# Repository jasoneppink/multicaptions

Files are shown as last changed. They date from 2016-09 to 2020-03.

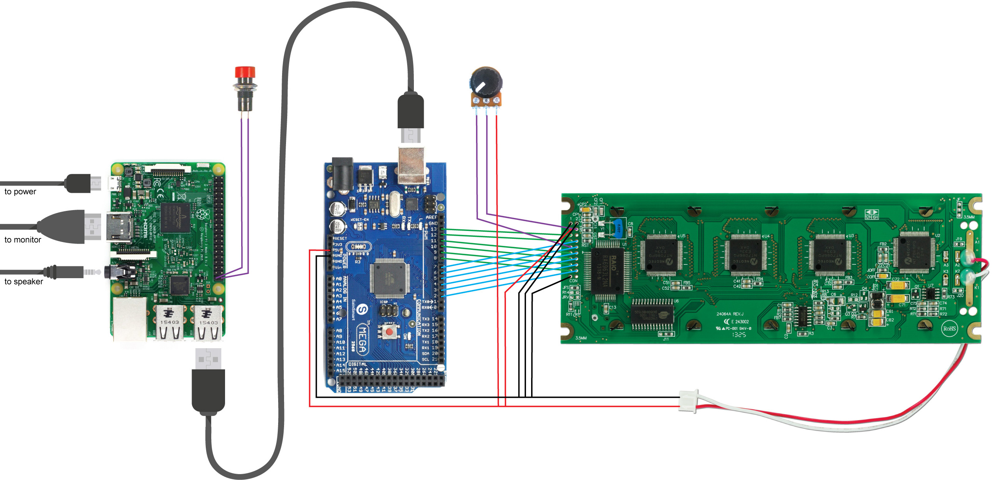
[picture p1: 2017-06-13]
docs/wiring.jpg

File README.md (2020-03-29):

# Multicaptions

Multicaptions is an open source captioning technology for media installations in museums, galleries, and other public institutions that accommodates opt-in viewing of captions in multiple languages without impinging on the video image.

Running on a Raspberry Pi, Multicaptions displays fullscreen video (up to full HD) while simultaneously processing and displaying subtitles in one or more selectable languages on a separate graphic LCD or VFD display. It is an affordable, easy-to-build, easy-to-maintain, open source project using completely off-the-shelf hardware.

Multicaptions is inspired by [Figaro System's Simultext](http://www.figaro-systems.com/simultextreg.html) (known as ["Met Titles"](http://www.nytimes.com/1995/10/02/arts/reinventing-supertitles-how-the-met-did-it.html?pagewanted=all) at the NYC Metropolitan Opera).

Sample setup (English)

## Hardware Requirements
* [Raspberry Pi 2 Model B or above](https://www.adafruit.com/product/3055)
* a monitor and HDMI cable
* cables and components
  * [5V 2.4 Amp power supply](https://www.adafruit.com/product/1995) for the Raspberry Pi
  * [microSD card](https://www.adafruit.com/product/102) for the Raspberry Pi (at least 4GB)
  * [pushbutton](https://www.adafruit.com/product/558) for cycling through languages (optional)
  * [jumper wires](https://www.adafruit.com/product/826) for connecting pushbutton (optional)
* LCD option
  * [Crystalfontz CFAG24064A graphic LCD display](https://www.crystalfontz.com/product/cfag24064attitz-240x64-display-module-graphic)
  * [Arduino Mega 2560](https://www.adafruit.com/product/191)
  * [A to B USB cable](https://www.adafruit.com/product/62) for connecting the Arduino to the Raspberry Pi
  * [10K potentiometer](https://www.adafruit.com/product/562) for setting the LCD display contrast
  * [jumper wires](https://www.adafruit.com/product/826) for connecting Arduino to LCD display
* VFD option
  * [Noritake GU256x64F-3900B Vacuum Fluorescent Display](https://www.noritake-elec.com/products/model?part=GU256X64F-3900B)
  * [RS-232 DE-9 to 7 pin Kit (with 24V power adapter)](http://noritake-vfd.com/sck-ca07pw06-n1.aspx)
  * [USB to RS-232 DB9 Serial Adapter](https://www.amazon.com/Plugable-Adapter-Prolific-PL2303HX-Chipset/dp/B00425S1H8)

## Setup and Installation
See [LCD](https://github.com/jasoneppink/multicaptions/tree/LCD) or [VFD](https://github.com/jasoneppink/multicaptions/tree/VFD) branches for detailed instructions.

## Notes
Multicaptions currently requires that SRT files for the same video have the same number of subtitles with the same start and end times, regardless of language, with a maximum of two lines per subtitle. (e.g. The demo video has 88 subtitles.)

## Thanks
* Big ups to @olikraus for their indispensible [u8g2 library](https://github.com/olikraus/u8g2), without which none of this would be possible.
* Many thanks to Moe Jangda for his work getting the Raspberry Pi to talk to the LCD display.
* High fives to [Sean McIntyre](https://github.com/boxysean) for refactoring my code.

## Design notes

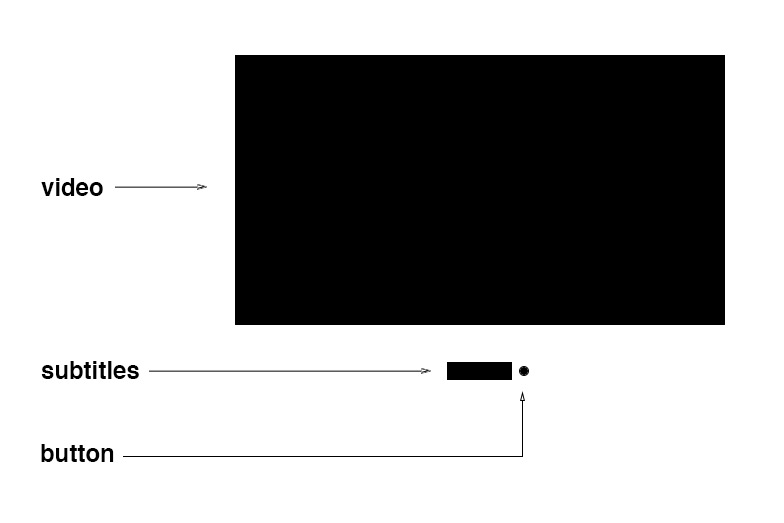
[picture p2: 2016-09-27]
docs/mockup_diagram.jpg

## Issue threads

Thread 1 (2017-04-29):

todo

jasoneppink, 2017-04-29:
- [x] create bash script to run at boot (based on [FluxVision startup.sh](https://github.com/jasoneppink/FluxVision/blob/master/startup.sh))
- [x] create dashboard script that replaces /etc/motd with relevant info (based on [FluxVision dashboard.py](https://github.com/jasoneppink/FluxVision/blob/master/dashboard.py))
- [x] design/fix [where language is placed on screen when switching languages](https://github.com/jasoneppink/extsub/blob/master/extsub.ino#L69)
- [x] create config file with following options using ConfigParser:
  - [x] title of video
  - [x] default language
  - [x] video filename (local to extsub.py)
  - [x] subtitle files directory (local to extsub.py)
  - [x] if LCD display launches (1) running subtitles in default language, (2) blank, or (3) with customizable text (e.g. "Press Button for Captions")
  - [x] if LCD display defaults to blank screen or customizable text, an "off/cancel" option allows the user who is cycling through languages to return to that default screen (blank or customizable text) rather than see subtitles
  - [x] if LCD display defaults to blank screen customizable text, determine if the display reverts to default screen (1) at end of video playback, (2) after returning to the same timecode when button was pressed, or (3) if it completes one full play through to the end (hits the end twice)
    - [x] reset to default language font if displaying customizable text

Closed 2017-10-20.

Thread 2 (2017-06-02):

wiring diagram error

jasoneppink, 2017-06-02:
The wires connecting Pin 4 and Pin 9 from the LCD display to the potentiometer are incorrect in the wiring diagram. Pin 4 should connect to the middle of the potentiometer and Pin 9 should connect to one of the outside pins.

jasoneppink, 2017-06-02:
Corrections made.

Closed 2017-06-02.

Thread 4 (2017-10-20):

Current todos (VFD branch)

jasoneppink, 2017-10-20:
- [ ] document C++ wrapper, wiring, etc.
- [ ] video/GIF of current tech
- [ ] document which languages are selected for what duration and display this info in dashboard
- [ ] update documentation to include button and optional header pins on LCD display
- [ ] better language select delays/timing (currently weird glitches, long waits)
- [ ] Arabic and Bengali support
- [ ] determine why VFD timing seems sluggish

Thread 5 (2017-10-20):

LCD todos (lower priority)

jasoneppink, 2017-10-20:
- [ ] try with Arduino Due (Mega 2560 doesn't have enough memory to use [u8g2_font_unifont_t_chinese3](https://github.com/olikraus/u8g2/wiki/fntgrpunifont), only chinese2)
- [ ] bug: pressing the button too quickly causes "LANGUAGE" to appear and (I think) causes a font / language mismatch. (I believe this happens when a language change that is being transmitted is interrupted with a second subsequent button press.)

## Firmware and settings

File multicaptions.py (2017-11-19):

#!/usr/bin/python
# -*- coding: utf-8 -*-

import re
import subprocess
from subprocess import Popen
import srt
import sys
from pprint import pprint
import time
import datetime
import getpass
import dbus
from langdict import langdict #Language Dictionary
import glob, os
import RPi.GPIO as GPIO
import collections
import serial as s
import serial.tools.list_ports
import ConfigParser
from dashboard import update_dashboard
import pickle
import io

#function converts timecode to milliseconds
def tc_to_ms(s):
        hours, minutes, seconds = (["0", "0"] + s.split(":"))[-3:]
        hours = int(hours)
        minutes = int(minutes)
        seconds = float(seconds)
        ms = int(3600000 * hours + 60000 * minutes + 1000 * seconds)
        return str(ms)

#omxplayer's timecode resolution is much higher than SRT files so this chops off the last 3 digits
def chop_digits(s):
        if long(s) > 999:
                return s[:-3]
        else:
                return "0"

def next_language(channel):
	global subtitles, language, next_i, write_subtitles, position, sub_start_position, subtitle_duration, played_through_once
	if(subtitle_duration == "2"):
		sub_start_position = position
		played_through_once = False
	j = 0
        while j < len(subtitles):
		if language == subtitles.items()[j][0]:
			if write_subtitles == True:
				if j+1 == len(subtitles):
					language = subtitles.items()[0][0]
					#revert to default
					if(launch_state != "subtitles"):
						ser.write("{DEFAULT" + launch_state + "}")
						write_subtitles = False
				else:
					language = subtitles.items()[j+1][0]
					ser.write("{LANGUAGE" + langdict[language] + language + "}")
				#for debugging language select button, print out date/time and language code
				sys.stdout.write(time.strftime("%Y-%m-%d %H:%M:%S", time.gmtime()) + ": " + language + "\n")
				break
			else:
				#keep language the same after first button press
				ser.write("{LANGUAGE" + langdict[language] + language + "}")
				write_subtitles = True
				break
		else:

			j += 1

def main():
	#get absolute path of this script
	abs_path = os.path.dirname(os.path.abspath(__file__)) + "/"

	#read from configuration file
	config = ConfigParser.ConfigParser()
	config.readfp(open(abs_path + 'config.txt', 'r'))
	default_lang = config.get('multicaptions config', 'default_lang')
	launch_state = config.get('multicaptions config', 'launch_state')
	video = abs_path + config.get('multicaptions config', 'video_filename')
	subtitle_directory = abs_path + config.get('multicaptions config', 'subtitle_directory')

	#initiate assorted variables for tracking subtitle duration
	subtitle_duration = config.get('multicaptions config', 'subtitle_duration')
	played_through_once = False
	sub_start_position = ""

	#create/write over .count_plays (number of playthroughs)
	f = open(abs_path + '.count_plays', 'w')
	f.write("0")
	f.close()

	#set up serial connection to Arduino
	ports = list(serial.tools.list_ports.comports())
	for p in ports:
	  if "ACM" in str(p):
	    arduino_port = str(p)[:12]
	ser=s.Serial(arduino_port, .9600)
	time.sleep(3)

	#set language, first from command line, otherwise from config.txt
	if(len(sys.argv) > 1):
		language = sys.argv[1]
	else:
		language = default_lang

	#send language to Arduino
	ser.write("{LANGUAGE" + langdict[language] + language + "}")

	#send default display state to Arduino
	ser.write("{DEFAULT" + launch_state + "}")

	#setup default display info
	if(launch_state == "subtitles"):
		write_subtitles = True
	else:
		write_subtitles = False

	#setup button
	GPIO.setmode(GPIO.BCM)
	GPIO.setup(21, GPIO.IN, pull_up_down=GPIO.PUD_UP) #GPIO21 = pin 40
	GPIO.add_event_detect(21, GPIO.FALLING, callback=next_language, bouncetime=200)

	#start omxplayer
	cmd = "omxplayer -o local --no-osd --loop %s" %(video)
	Popen([cmd], shell=True)

	#start dbus
	done, retry = 0, 0
	while done==0:
		try:
			with open('/tmp/omxplayerdbus.' + getpass.getuser(), 'r+') as f:
				omxplayerdbus = f.read().strip()
			bus = dbus.bus.BusConnection(omxplayerdbus)
			object = bus.get_object('org.mpris.MediaPlayer2.omxplayer','/org/mpris/MediaPlayer2', introspect=False)
			dbusIfaceProp = dbus.Interface(object,'org.freedesktop.DBus.Properties')
			dbusIfaceKey = dbus.Interface(object,'org.mpris.MediaPlayer2.Player')
			#disable in-player subtitles on video
			dbusIfaceKey.Action(dbus.Int32("30"))
			done=1
		except:
			retry+=1
			if retry >= 5000:
				print "ERROR"
				raise SystemExit

	#import SRT subtitle files into one "subtitles" dict
	subtitles = collections.OrderedDict()
	os.chdir(subtitle_directory)

	#first add default language
	for subs in glob.glob("*.srt"):
	        lang = subs.split('.')[1]
		if(lang == default_lang):
		        with io.open(subs, "r", encoding="utf-8-sig") as myfile:
		                subfile = myfile.read()
		        subtitle_generator = srt.parse(subfile)
		        subtitles[lang] = list(subtitle_generator)

	#then add other languages
	for subs in glob.glob("*.srt"):
		lang = subs.split('.')[1]
		with io.open(subs, "r", encoding="utf-8-sig") as myfile:
			subfile = myfile.read()
		subtitle_generator = srt.parse(subfile)
		subtitles[lang] = list(subtitle_generator)

	#iterate through and print subtitles	
	i = 0
	next_i = 0
	position = "0"
	duration = "0"
	while duration == "0":
		try:
			duration = chop_digits(str(dbusIfaceProp.Duration()))
		except:
			pass

	while long(duration) > long(position):
		start = tc_to_ms(str(subtitles[language][i].start))
		end = tc_to_ms(str(subtitles[language][i].end))
		position = chop_digits(str(dbusIfaceProp.Position()))

		#return to default if subtitle_duration 2 cases are met
		if subtitle_duration == "2" and write_subtitles == True and played_through_once == True:
			if long(position) > long(sub_start_position):
				write_subtitles = False
				ser.write("{DEFAULT" + launch_state + "}")

		if long(position) > long(start) and long(position) <= long(end):
			if i > next_i:
				next_i += 1
			elif i == next_i:
				#requires write_subtitles = True to account for launch_state
				if write_subtitles == True:
					ser.write(subtitles[language][i].content.encode("utf-8") + "\r")
				next_i += 1
		elif long(position) > long(end):
			if subtitles[language][i] == subtitles[language][-1]:
				i = 0
				next_i = 0
				if launch_state != "subtitles" and write_subtitles == True:
					if(subtitle_duration == "1" or (subtitle_duration == "3" and played_through_once == True)):
						#return dipslay to default state
						write_subtitles = False
						played_through_once = False
						language = default_lang
						ser.write("{DEFAULT" + launch_state + "}")
					elif(subtitle_duration == "3" and played_through_once == False):
						played_through_once = True
					elif(subtitle_duration == "2"):
						played_through_once = True
				#update .count_plays (number of playthroughs)
				with open(abs_path + '.count_plays', 'r') as count_video:
					value = int(count_video.read())
				with open(abs_path + '.count_plays', 'w') as count_video:
					count_video.write(str(value + 1))

				#write to /etc/motd
				update_dashboard()
			else:
				i += 1
		elif long(position) == 0:
			i = 0
			next_i = 0

if __name__ == '__main__':
	main()

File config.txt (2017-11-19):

[multicaptions config]

# VIDEO TITLE
# for identification upon logging in via SSH
video_title = Sesame Street: Kermit And Cookie Monster And The Mystery Box

# DEFAULT LANGUAGE
# as 3-character ISO 639-2B
default_lang = eng

# VIDEO FILENAME
# Location of video, relative to multicaptions.py
video_filename = media/test.mp4

# SUBTITLE DIRECTORY
# Location of subtitle file directory, relative to multicaptions.py. Don't add slashes
subtitle_directory = media

# DEFAULT DISPLAY STATE
# default state of the LCD display on launch
# options: "blank" or "subtitles", any other text will be displayed verbatim
# on launch (e.g. "Press Button for Subtitles")
launch_state = Press Button for Captions

# SUBTITLE DURATION BEFORE RETURN TO DEFAULT
# If the default state is "blank" or custom text, how long do the subtitles
# display before returning to default state?
# options: 1: to the end, 2: once around, 3: once around to the end
subtitle_duration = 1

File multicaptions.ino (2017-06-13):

#include <U8g2lib.h>

U8G2_T6963_240X64_F_8080 u8g2(U8G2_R0, 11, 5, 10, 4, 9, 3, 8, 2, /*enable=lcd_7*/ 12, /*cs= lcd_5 */ 13, /*dc=lcd 8 c/d */ 7, /*reset=pin10 green*/ 6); // Connect RD with +5V, FS0 and FS1 with GND

String inputString;                     //holds incoming subtitle data
boolean stringComplete = false;         //whether the line of text is complete and ready to be printed to the display

String defaultLanguageCode = "";        //first language sent

String language;                        //holds incoming language data
String languageCode;                    //current language (three characters in ISO 639-2B format e.g. "eng")
String displayLanguage;                 //language to display on screen
boolean newLanguage = false;            //whether a language has been detected

String launchState = "blank";           //is display default blank ("blank"), shows subtitles ("subtitles"), or shows instructions (custom)
String displayLaunchState;              //default text to display on screen
boolean newLaunchState = false;         //whether instructions have been detected to return to launch state

unsigned long displayPause;             //test for whether subtitles are temporarily disabled while language name is displayed 

String line1;
String line2;

//location of text on display
int x = 5;
int line1_y = 20;
int line2_y = 40;

void setup(void) {
  // initialize serial:
  Serial.begin(9600);
  
  u8g2.begin();
  u8g2.enableUTF8Print();
  u8g2.setFontDirection(0);
  
  //Default to Latin characters (English, French, Spanish, etc.)
  u8g2.setFont(u8g2_font_helvR10_tf);
  
  //clear the internal memory
  u8g2.clear();

  //print "Ready..."
  u8g2.setCursor(x, line1_y);
  u8g2.print("Ready...");
  u8g2.sendBuffer();
  u8g2.clearBuffer();
}


void loop() {
  //switch to the correct font based on language
  if (newLanguage) {
    //Serial is sent as "{LANGUAGE[display language][3-letter language code]}" e.g. {LANGUAGEEnglisheng} or {LANGUAGEespañolspa}
    displayLanguage = language.substring(8, language.length()-3); 
    languageCode = language.substring(language.length()-3, language.length());
    if(defaultLanguageCode == "") {
      defaultLanguageCode = languageCode;
    }

    setFont(languageCode);
  
    //print the new language
    printCenteredText(displayLanguage);
    displayPause = millis();
    newLanguage = false;
  }

  if (newLaunchState) {
    //Serial is sent as "{DEFAULT[display instructions]}" e.g. {DEFAULTblank} or {DEFAULTsubtitles}
    displayLaunchState = launchState.substring(7, launchState.length());
   
    if (displayLaunchState == "blank") {
      u8g2.clear();
    } else if (displayLaunchState != "subtitles") {
      setFont(defaultLanguageCode);
      printCenteredText(displayLaunchState);
    }
    newLaunchState = false;
  }

  //if we're not paused on a display language
  if((millis() - displayPause) > 500) {
    //print the lines when everything has arrived via serialEvent()
    if (stringComplete) {
        u8g2.clearBuffer();
     
        //clear the internal memory
        u8g2.firstPage();
        do {
           u8g2.setCursor(x, line1_y);
           u8g2.print(line1);
           line1 = "";
           u8g2.setCursor(x, line2_y);
           u8g2.print(line2);
           line2 = "";
        }
        while ( u8g2.nextPage() );
        stringComplete = false;
    }
  //otherwise clear out any text that may have come in during the display language pause
  } else {
    line1 = "";
    line2 = "";
    stringComplete = false;
  }
}

void printCenteredText(String text) {
    u8g2.clearBuffer();
    char textChar[text.length()+1];
    text.toCharArray(textChar, text.length()+1);
    int textWidth = u8g2.getUTF8Width(textChar);
    u8g2.setCursor((240-textWidth)/2, 36);
    u8g2.print(text);
    u8g2.sendBuffer(); 
}

void setFont(String lang) {
  if(lang=="eng" || lang=="fre" || lang=="hat" || lang=="spa") {
    u8g2.setFont(u8g2_font_helvR10_tf);
  } else if(lang=="ara") {
    u8g2.setFont(u8g2_font_unifont_t_arabic);
  } else if(lang=="ben") {
    //no Bengali font yet
  } else if(lang=="chi") {
    u8g2.setFont(u8g2_font_unifont_t_chinese2);
  } else if(lang=="kor") {
    //no Korean font yet
  } else if(lang=="rus") {
    u8g2.setFont(u8g2_font_unifont_t_cyrillic);
  } else if(lang=="urd") {
    //no Urdu font yet
  }
}

/*
SerialEvent occurs whenever new data comes in the
hardware serial RX. This routine is run between each
time loop() runs, so using delay inside loop can delay
response. Multiple bytes of data may be available.
*/
void serialEvent() {
  while (Serial.available()) {
    //get the new byte:
    char inChar = (char)Serial.read();

    //detect language
    if (inChar == '{') {
      //indicates beginning of new instruction string, so clear what came before
      inputString == "";
    } else if(inChar == '}') {
      //indicates end of new instruction string
      if (inputString.substring(0,8) == "LANGUAGE") {
        newLanguage = true;
        language = inputString;
      } else if(inputString.substring(0,7) == "DEFAULT") {
        newLaunchState = true;
        launchState = inputString;
      }
      //clear string
      inputString = "";
    } else {
      //add character to the inputString:
      inputString += inChar;
    }
    
    //split into lines
    if (inChar == '\n') {
      line1 = inputString;
      inputString = "";
    } else if (inChar == '\r') {
      if (line1 == "") {
          line1 = inputString;
      } else {
        line2 = inputString;
      }
      inputString = "";
      stringComplete=true;
    }
  }
}

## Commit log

2016-09-27 schematic (for Fritzing)
    [schematic.fzz]
2016-09-27 added schematic and dependencies
2017-04-21 add Arduino sketch
2017-04-24 automatically detects Arduino
2017-04-28 new wiring diagram
2017-04-28 now with wiring diagram!
2017-04-28 getting closer on button press language switching
2017-04-28 better language switching
2017-04-28 adds language switching by button
2017-04-28 made wiring a whole lot simpler
2017-04-28 sample GIF
2017-05-03 now with bootstrapping
    [config.txt]
2017-05-03 now with MOTD dashboard
    [config.txt]
2017-05-17 new default display options (blank, custom message, or already playing default language subtitles
    [config.txt]
2017-05-18 new subtitle durations feature
    [config.txt]
2017-06-02 corrected/updated wiring diagram
2017-06-02 updated/corrected wiring diagram
2017-06-02 wiring correction
2017-11-19 new project name
    [config.txt]
